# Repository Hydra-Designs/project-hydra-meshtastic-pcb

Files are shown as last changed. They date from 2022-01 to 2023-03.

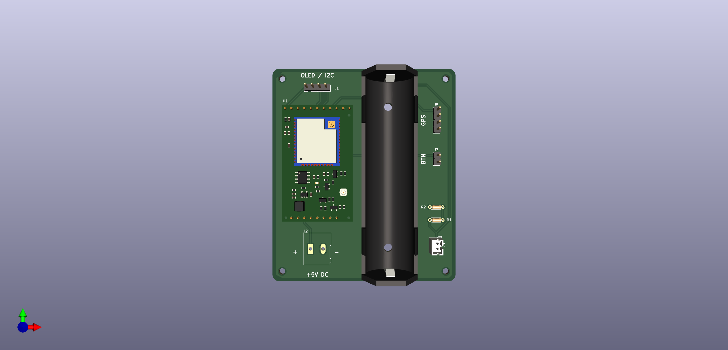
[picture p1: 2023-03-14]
Hydra Base/Hydra Base.png

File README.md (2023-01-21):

# Project Hydra (Meshtastic PCB)




A minimalist PCB design built around the Ebyte E22-900M30S 30dbm (1 watt) LoRA radio and the ESP32-WROOM-32U cpu compatible with the [Meshtastic-device](https://github.com/meshtastic/Meshtastic-device) firmware. 



## Features
- Supports up to 30dbm (1 watt) transmit power *(Please check local ISM band regulations for power limitations)*
- OLED support via I2C
- GPS support via UART
- PSRAM support
- User button via pin header
- Switchable 3.3V power rail (GPS power saving)
- ADC input for battery voltage sensing
- Single 5V input (no reverse polarity and overvoltage protection!)
- 3.3V output (or input if onboard buck converter is not assembled)
- Two GPIO reserved for future use (for example power control)
- Programmable via USB-Serial adapter (RTS/DTR are required for the on-board auto reset!)
- Compatible with "meshtastic-diy-v1" target in Meshtastic-device firmware

## Project status
- V2.1 has been published and introduces breaking changes.
- Production file generation has not been verified yet for all variants.
- Core PCB KiCad footprint and schematic symbol will be available afer the official V2 release.

## Ordering from JLCPCB
- Basic ordering instructions can be found at the [ordering page](ordering.md).

## Assembly instructions
- Use the fancy iBom for reference!
- Start with the 3.3v step down regulator and test the 3.3v rail first.
- Assemble all the parts for the auto reset circuit and the ESP32 module. Don't forget to connect the 2.4G antenna!
- Try to program the core pcb next.
- Lastly, populate the RF modem. You can use a strip of cardboard as a spacer to leave a small gap between the two PCBs, in case the ESP32 stops working you can use solder wick to easily remove and reuse the RF modem.
- Never ever turn on the core pcb withount an antenna! This may infuriate the RF gods and you inevitably end up performing a sacrifial ritual to please the RF gods with magic smoke.
- PSRAM is optional

## Contributing

Please contribute using [Github Flow](https://guides.github.com/introduction/flow/). Create a branch, add commits, and [open a pull request](https://github.com/PlumRugOfDoom/project-hydra-meshtastic-pcb/compare/).

## Support

Please [open an issue](https://github.com/PlumRugOfDoom/project-hydra-meshtastic-pcb/issues/new) for support.

## License
[GPL v3](https://choosealicense.com/licenses/gpl-3.0/)

[Meshtastic](https://meshtastic.org/)® is a registered trademark of Meshtastic LLC. Meshtastic software components are released under various licenses, see github for details. No warranty is provided - use at your own risk.

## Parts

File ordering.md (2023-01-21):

# Ordering from JLCPCB

Download the Gerber-JLCPCB.{version}.zip file and the .zip file of the desired variant from the [Release](https://github.com/Hydra-Designs/project-hydra-meshtastic-pcb/releases/tag/2.1) and extract it to a local folder.


Navgate to https://cart.jlcpcb.com/quote to start an order by uploading the gerber zip file.



After the gerber file is loaded, select the quantity.

Enable the SMT Assembly section. Select "Assemble top side", choose a quantity, and for Tooling holes select "Added by Customer".
Click confirm to continue.


Upload the BoM-JLCPCB and CPL-JLCPCB .csv files from the unzipped variant directory and click next.


Review the parts list from the BoM and click Next. Manual changes to the BoM / CPL to swap equivalent parts out due to inventory shortages. 
Optionally, you can ignore these parts and source them from another vendor and manually solder them.


Review the placement of the components from the CPL and hit Save to Cart.


After this process is complete, you can choose shipping and payment method at the checkout.


# Final assembly 

Ebyte E22-900M30S and ESP32-WROOM-32UE-N16 modules as well as any out of stock parts will need to be purchased from LCSC or a preferred vendor. You will be responsible for [hand soldering](README.md#assembly-instructions) these components onto the board. Use the iBoM html file for component placement assistance.

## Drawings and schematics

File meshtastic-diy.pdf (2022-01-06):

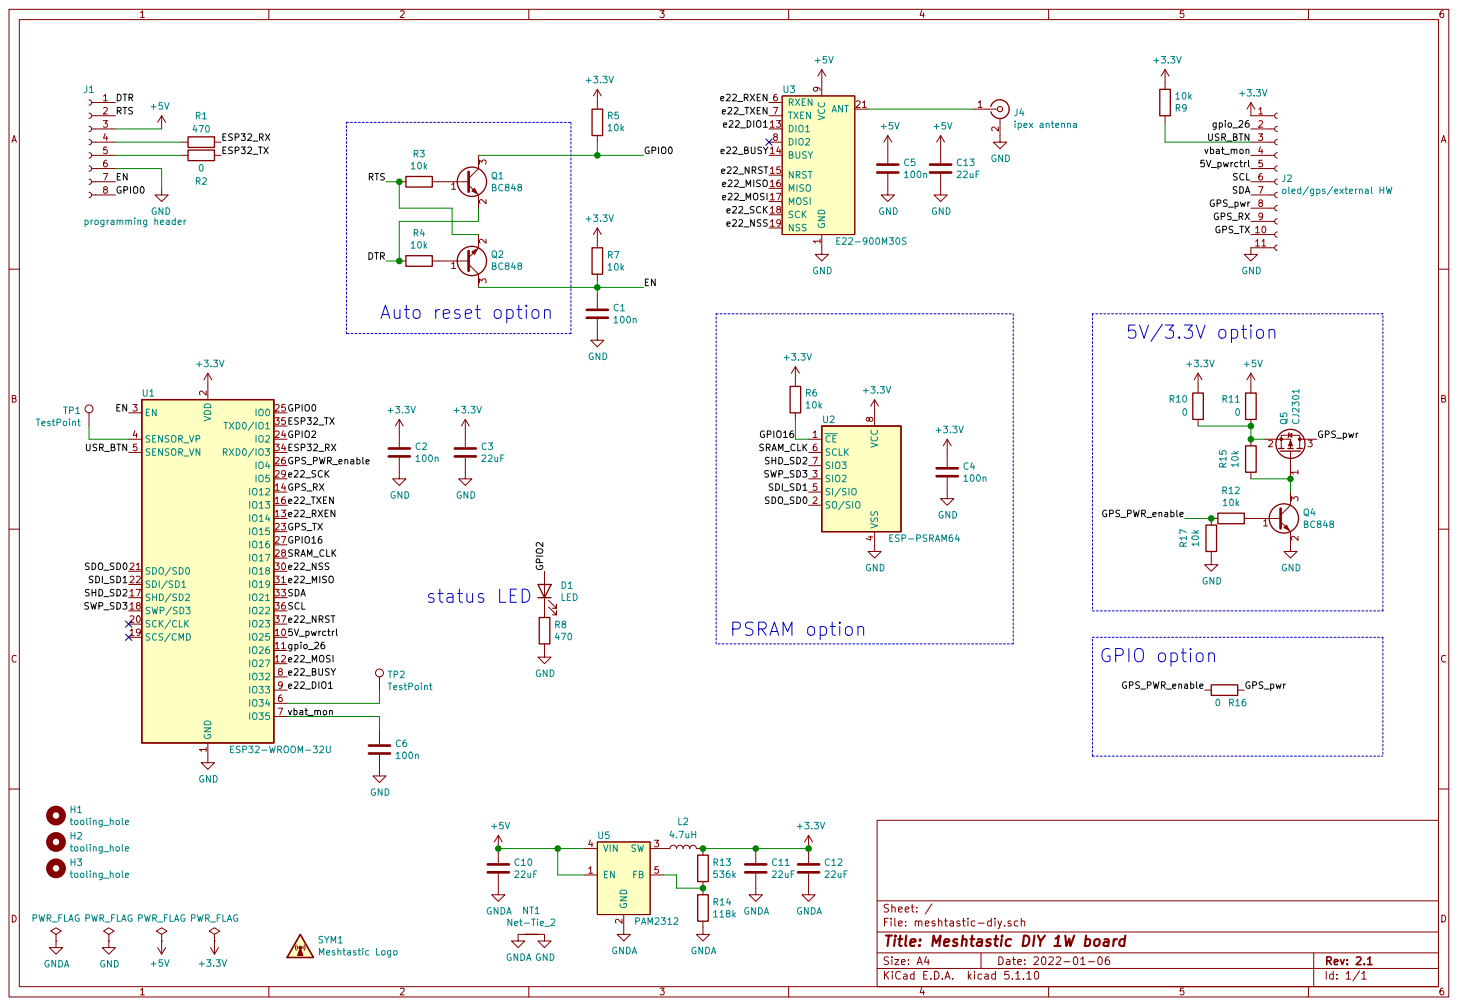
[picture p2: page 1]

1 DIO1 13 BUSY 14 NRST 15 MISO 16 MOSI 17 SCK 18 NSS 19 ANT RXEN 21

2 SCK/CLK 20 SDO/SD0 21 SDI/SD1 22

4 SI/SIO 5 SCLK 6 SIO3 7 VCC

Id: 1/1 Title: Meshtastic DIY 1W board

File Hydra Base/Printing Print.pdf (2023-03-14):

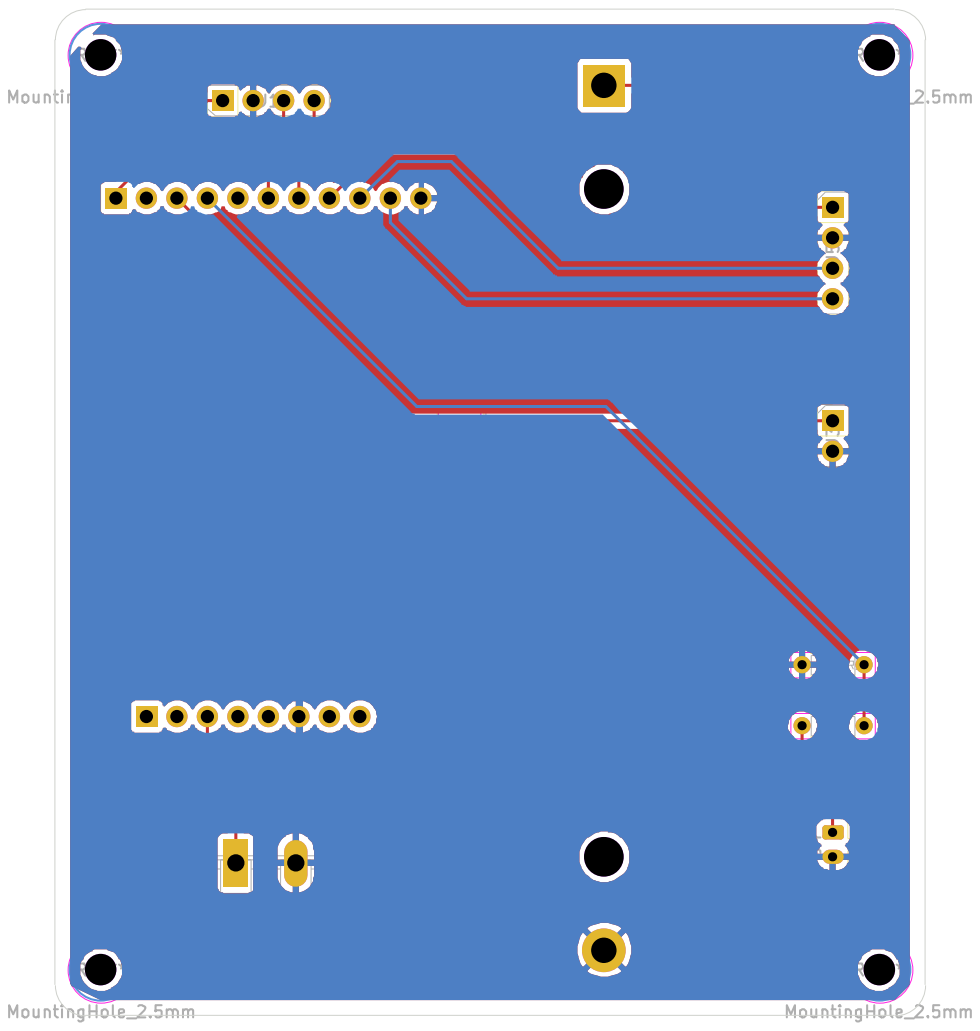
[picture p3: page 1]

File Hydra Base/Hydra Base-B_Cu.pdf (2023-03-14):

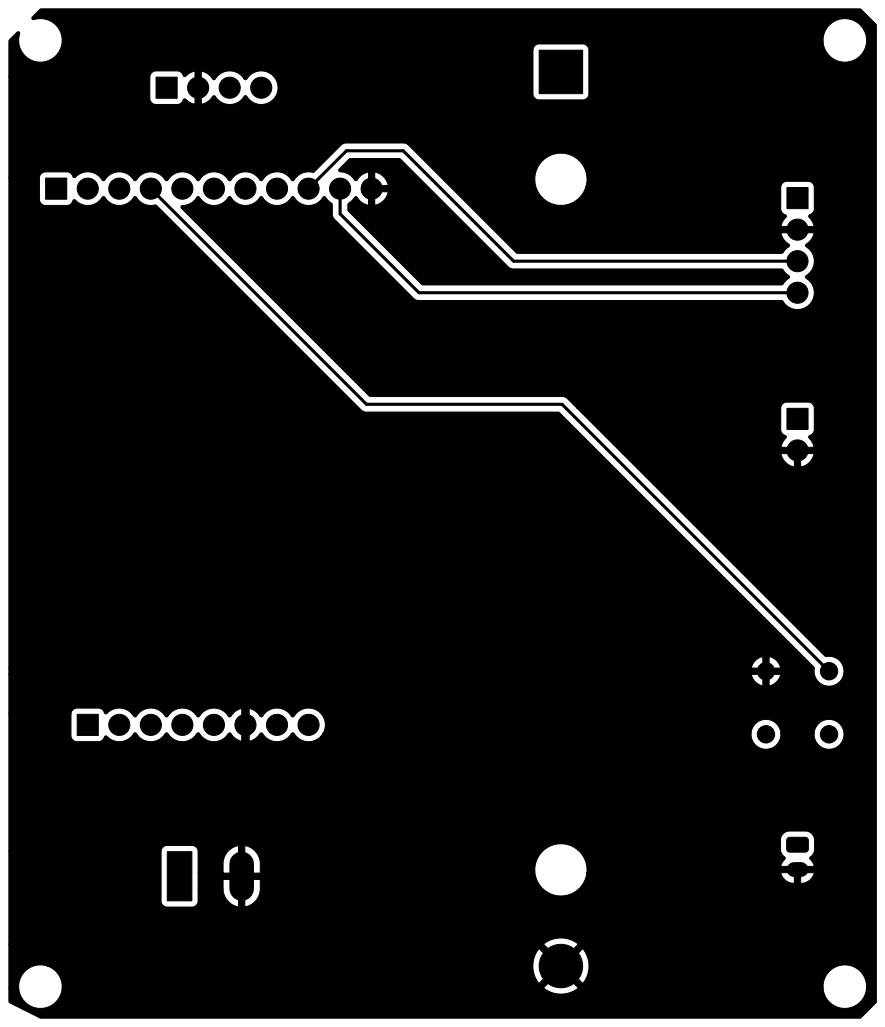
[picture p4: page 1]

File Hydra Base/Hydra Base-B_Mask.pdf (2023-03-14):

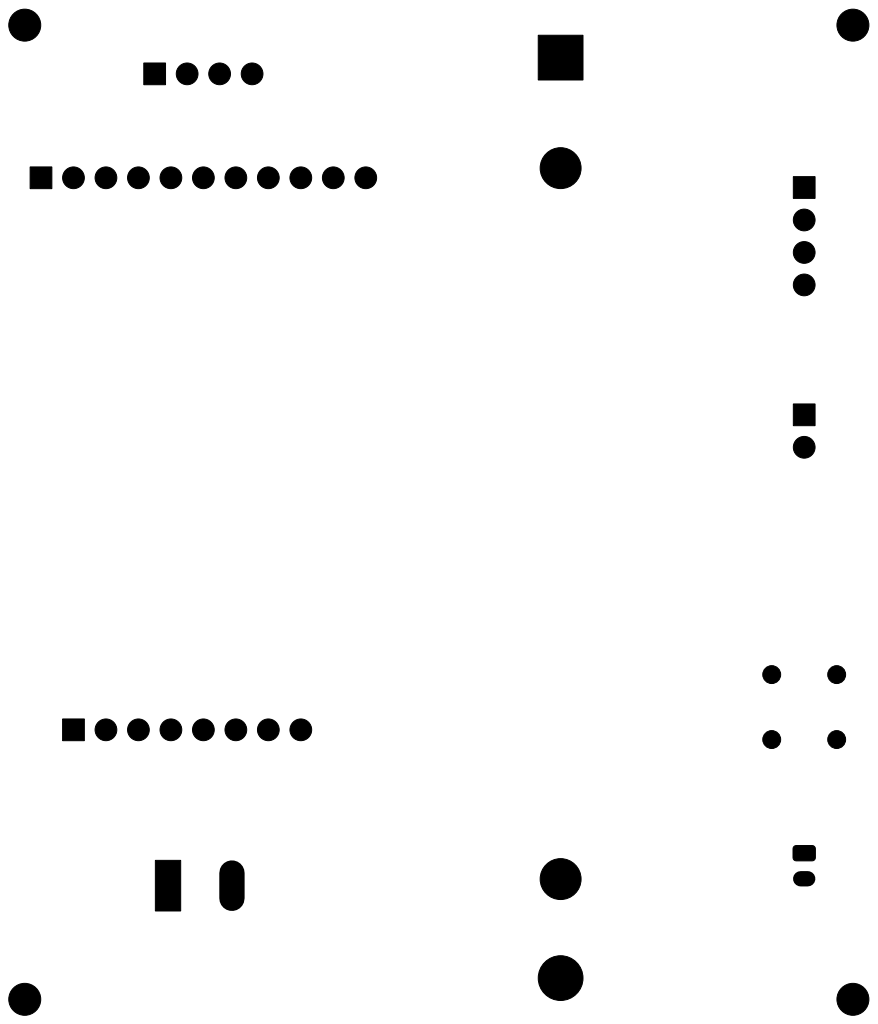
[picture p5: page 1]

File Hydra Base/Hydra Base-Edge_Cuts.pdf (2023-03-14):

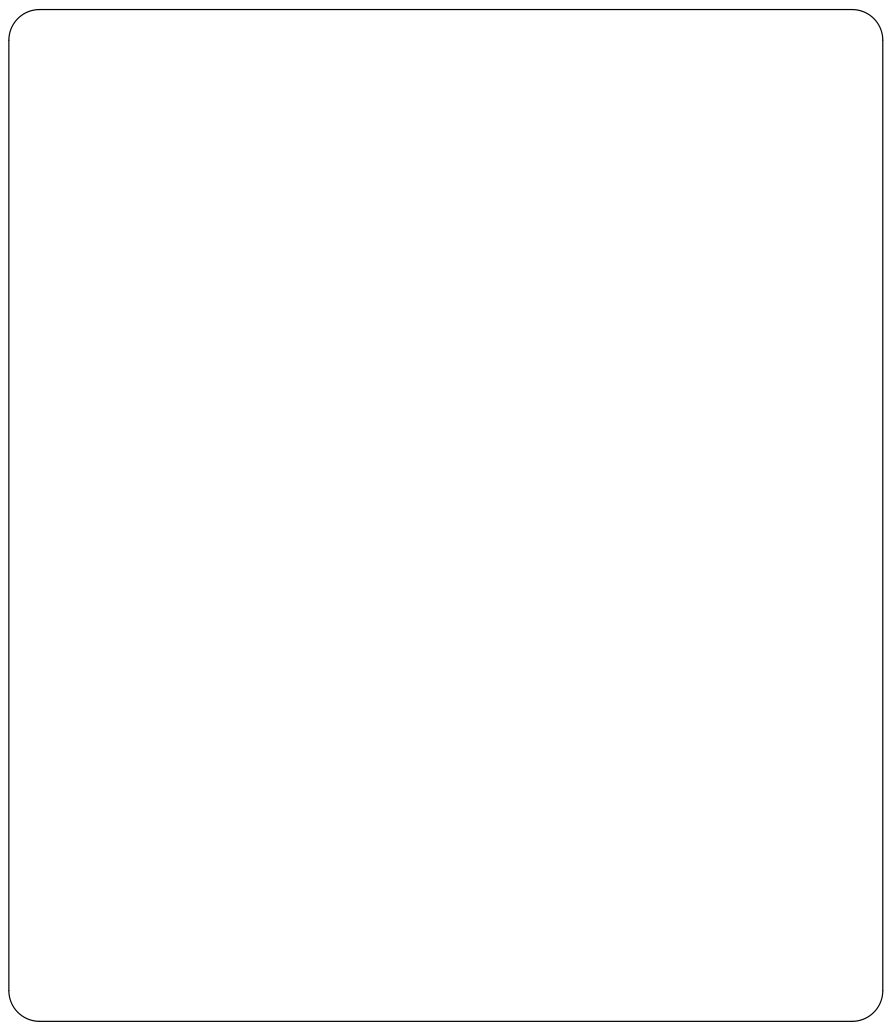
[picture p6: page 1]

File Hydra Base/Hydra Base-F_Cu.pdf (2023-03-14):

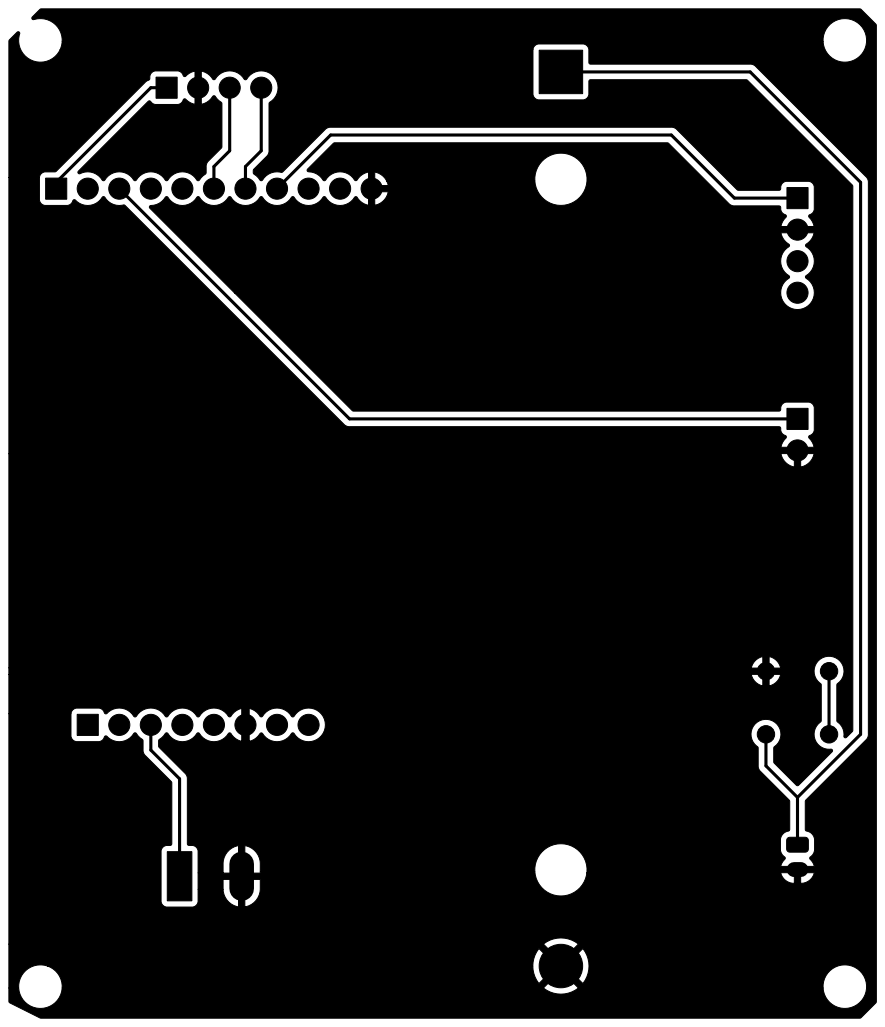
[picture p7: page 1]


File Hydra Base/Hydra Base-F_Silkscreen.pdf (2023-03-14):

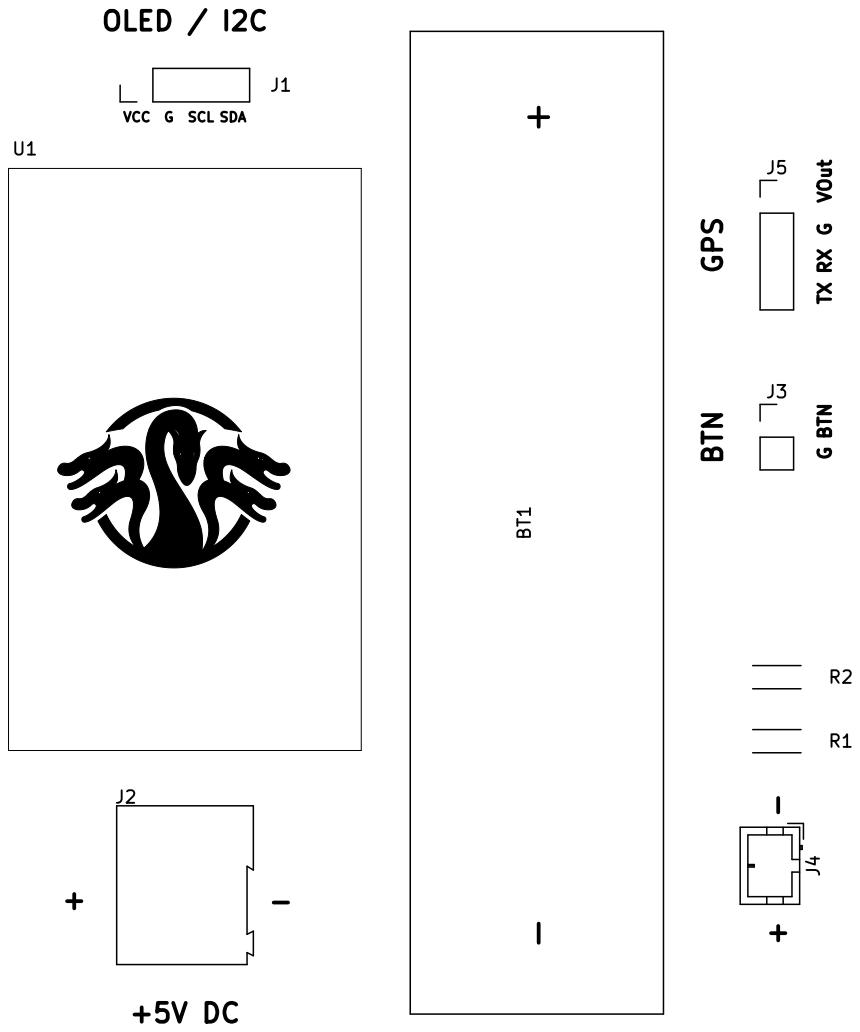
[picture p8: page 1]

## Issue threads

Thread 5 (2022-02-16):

ESP-PSRAM64 Part Number

RicInNewMexico, 2022-02-16:
In v2.1 the BoM and all other files list the PSRAM module as simply "ESP-PSRAM64".

The espressif datasheet [HERE](https://www.espressif.com/sites/default/files/documentation/esp-psram64_esp-psram64h_datasheet_en.pdf) shows ESP-PSRAM64 as being the version intended for 1.8v operating voltage and ESP-PSRAM64H as the correct version for 3.3v

Is this a typo? Just want to clarify it, I'm looking at having some assembled pcbs made here in the near future.

Thanks!

Ric

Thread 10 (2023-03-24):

Just a Question about DIY

richonguzman, 2023-03-24:
I've build a few APRS trackers with Lora + Gps and ESP32 Wroom and Wemos Mini S2

I don't find a way to read and mod some code to make my own Meshtastic devices.

could anyone help me gettin' started?

tmarkson, 2023-08-02:
I think you'll want to start in the Firmware section of the Meshtastic docs: https://meshtastic.org/docs/development/firmware

Specifically start here to setup the build env. https://meshtastic.org/docs/development/firmware/build#setup-the-build-environment

After you can build the code, you can modify the code.

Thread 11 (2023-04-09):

Is it possible to buy an assembled board?

Telepresent, 2023-04-09:
Hi,

I would like to know if it is possible to buy it.

tmarkson, 2023-08-02:
The creators have made a create page about ordering your own device: https://github.com/Hydra-Designs/project-hydra-meshtastic-pcb/blob/main/ordering.md

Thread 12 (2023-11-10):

JLCPCB component alternatives

Fexiven, 2023-11-10:
Hey there, i was about to order a few PCBs, sadly the ESP-PSRAM64 (U2) and  Power Inductors (L2) are out of stock. Could you please help me there to get the right component alternatives?

Thank you

Fexiven, 2023-11-10:
I ordered now with U2 VTI7064MSME and L2 MWSA0402S-4R7MT

Closed 2023-11-10.

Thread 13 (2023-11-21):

Code -2

Fexiven, 2023-11-21:
Today i assembled all parts

Sadly i only get Error -2 when i try to initialize the SX1268 Module with

`SX1268 radio = new Module(18, 33, 23, 32)`

Theres definietly no short or a bad solder connection.

Please Help

Fexiven, 2023-11-21:
That was an issue from the Meshtastic firmware. I opened an PR to fix it

Closed 2023-11-21.

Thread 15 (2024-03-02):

J4 polarity and L2 too big

danshamradio, 2024-03-02:
Hi I got a message from JLCPCB when making a few boards that they are not sure of the polarity of j4 and that l2 has too big of a footprint

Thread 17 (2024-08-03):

ESP32 / ESP-PSRAM64

slawekbikeman, 2024-08-03:
Hi, I am building my own version of the Meshtastic module based on the Hydra schematic. PSRAM comes in two models, powered by 1.8V (ESP-PSRAM64) and 3.3V (ESP-PSRAM64H). The Hydra schematic has the ESP-PSRAM64 symbol. However, the power supply is connected to 3.3V. So I used the ESP-PSRAM64H circuit, as the specification requires it to be powered by 3.3V. Unfortunately, ESP32 does not work with the memory. It does not see it at all. Is the ESP-PSRAM64 symbol (1.8V) on the schematic correct and is that the reason it does not work? Or is the ESP-PSRAM64H (3.3V) circuit correct, but the problem may be somewhere else?

TIA

--
Slawek Bikeman

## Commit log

2021-10-23 dc/dc converters added suggestion for 5V enable -> simple deep discharge protection via esp32 (self power off)
    [meshtastic-diy.sch]
2021-10-23 schematic pdf updated
2021-10-25 3.3v step down layouted
    [meshtastic-diy.kicad_pcb, meshtastic-diy.sch]
2021-10-28 cleanup, layout finished
    [meshtastic-diy.kicad_pcb, meshtastic-diy.sch]
2021-10-28 GPIO swapped
    [meshtastic-diy.kicad_pcb, meshtastic-diy.sch]
2021-11-07 final layout cleanup, 3.3v reg layout improved, 100n decoupling cap for vbat added, meshastic logo added
    [meshtastic-diy.kicad_pcb, meshtastic-diy.sch]
2021-11-07 Remove silkscreen layers from JLCPCB gerber KiBot config (#2)
2021-11-08 Add iBoM to bill of materials confoig
2021-11-08 Added "the works" in terms of release artifacts (#3)
    * Create jlcpcb.render.config.kibot.yaml
    * Include iBoM in Release assetts
    * Rename build-jlcpcb-artifacts.yml to build-artifacts.yml
    * Added schematic and rendering outputs to kibot config
    * iBoM asset type fix and added renders to artifacts
    * Fixed release dependency
    * Fixed ibom path
    * Removed dir from image render
    * Added renders to release assets
2021-11-08 3.3v step down inductor fixed.
    [meshtastic-diy.kicad_pcb]
2021-11-08 silkscreen aligned
2021-11-08 Added gitignore for kicad files and removed stuff
2021-11-08 Updated board image
2021-11-10 position of 3.3v step down net tie modified
    [meshtastic-diy.kicad_pcb]
2021-11-11 3.3v buck voltage divider wrong values
    [meshtastic-diy.sch]
2021-11-12 Update from V1.0 to V2.0: -add compatibility with wESP32-Prog submodule -!NO BACKWARDS COMPATIBILITY WITH V1.0 CORE PCB PINOUT!
    [meshtastic-diy.kicad_pcb, meshtastic-diy.sch]
2021-11-12 minor schematic cleanup
    [meshtastic-diy.sch]
2021-11-12 schematic pdf update
2021-11-12 silkscreen aligned, jlc board identifier position added
    [meshtastic-diy.kicad_pcb]
2021-11-22 README update
    [meshtastic-diy.kicad_pcb]
2021-12-30 bump to v2.1, new logo (silk and mask), all parts now have LCSC part numbers, voltage divider modified (3.325 with available resistors)
    [meshtastic-diy.kicad_pcb, meshtastic-diy.sch]
2021-12-30 minor schematic mods
    [meshtastic-diy.sch]
2021-12-30 L2 rotated by 180°
    [meshtastic-diy.kicad_pcb, meshtastic-diy.sch]
2021-12-30 Update jlcpcb.bom.config.kibot.yaml
    just for testing purposes
2021-12-30 Exclude e22 with filter hopefully
2021-12-30 E22 filter regex
2021-12-30 fix for missing L2
    [meshtastic-diy.kicad_pcb, meshtastic-diy.sch]
2021-12-30 forgot to set THT filter true...
2021-12-30 add LCSC# for C3
    [meshtastic-diy.sch]
2021-12-30 fix for wrong u.fl orientation
    [meshtastic-diy.kicad_pcb, meshtastic-diy.sch]
2021-12-30 fix for u.fl part rotation, tooling holes added
    [meshtastic-diy.kicad_pcb, meshtastic-diy.sch]
2021-12-31 exclude ESP32 from CPL
2021-12-31 Consolidate filters
2021-12-31 L2 swapped
    [meshtastic-diy.sch]
2022-01-01 exclude_auto_prog filter
2022-01-01 Hopefully config is correct for variants
    [meshtastic-diy.sch]
2022-01-01 Experimenting with variants instead of filters
2022-01-01 Removed now defunct dnf filter
2022-01-01 Blacklisting for variants instead
    [meshtastic-diy.sch]
2022-01-01 R1/R2 changed to mach espressif devkit. Also, brighter status LED
    [meshtastic-diy.sch]
2022-01-01 Added config for variants back
    [meshtastic-diy.sch]
2022-01-02 pin headers now have equal distance to pcb edge
    [meshtastic-diy.kicad_pcb]
2022-01-02 lower right tooling hole readjusted
    [meshtastic-diy.kicad_pcb]
2022-01-02 I must be tired
2022-01-02 Schematic variants
2022-01-02 major PCB overhaul
    [meshtastic-diy.kicad_pcb]
2022-01-02 pcb cleanup
    [meshtastic-diy.kicad_pcb]
2022-01-02 silkscreen realigned
    [meshtastic-diy.kicad_pcb]
2022-01-02 improved silscreen alignment
    [meshtastic-diy.kicad_pcb]
2022-01-02 more space for L2
    [meshtastic-diy.kicad_pcb]
2022-01-02 keepout zone around L2
    [meshtastic-diy.kicad_pcb]
2022-01-02 keepout zone around L2 increased
    [meshtastic-diy.kicad_pcb]
2022-01-03 pin headers aligned to 100mil grid, new variants
    [meshtastic-diy.kicad_pcb, meshtastic-diy.sch]
2022-01-03 GPS RX/TX swapped
    [meshtastic-diy.kicad_pcb, meshtastic-diy.sch]
2022-01-04 increased GND track width
    [meshtastic-diy.kicad_pcb]
2022-01-05 Update jlcpcb.full.config.kibot.yaml
    remove unnecessary layers, add silkscreen
2022-01-05 silk removed from logo
    [meshtastic-diy.kicad_pcb]
2022-01-06 switchable rail simplified and improved
    [meshtastic-diy.kicad_pcb, meshtastic-diy.sch]
2022-01-08 More DNF filters
2022-01-08 logo set as virtual
    [meshtastic-diy.kicad_pcb]
2022-04-02 svg pcb
2023-01-21 Updating part to reflect non EOL part (#7)
    Updating to new part as seen here
    https://www.mouser.com/ProductDetail/356-ESP32WRM32UE28UH
    Old part is EOL.
2023-03-14 Footprint (#6)
    * Start of footprint / symbol for core
    * schematic symbol pins rearranged
    * footprint fixed
    * Update .gitignore
    * Ignore backups
    * More backups
    * Primitive base board example
    ---------
    [Hydra Base-B_Cu.gbr, Hydra Base-B_Mask.gbr, Hydra Base-B_Paste.gbr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]
